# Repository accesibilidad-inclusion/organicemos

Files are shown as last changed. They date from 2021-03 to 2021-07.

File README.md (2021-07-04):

# Organicemos

## Contexto

[Para mayor información acerca de la investigación acerca de la investigación realizada en el proyecto de Apoyos a la vida independiente de adultos con discapacidad intelectual haga click aquí](https://wiki.ead.pucv.cl/Apoyos_a_la_vida_independiente_de_adultos_con_discapacidad_intelectual:_Organizador_colaborativo)

La vida independiente es considerada un derecho de las personas con discapacidad, además de ser un factor clave para el fomento de la calidad de vida de estas personas. Esta investigación se desarrolla en Chile, país en el que no se encuentran tan desarrolladas las materias de derechos ni oportunidades para la vida independiente de este grupo históricamente vulnerado. 

El panorama internacional actual demuestra que el uso de tecnologías asistivas como apoyo para diversos aspectos de la vida de las personas con discapacidad, pueden llegar a generar un cambio positivo en sus vidas.

Dentro de este mundo, se suelen encontrar aquellas que apoyan las funciones primarias de la vida de estas personas, las cuales se desarrollan en base a un estudio de sus capacidades. En este proyecto, a través de un proceso de diseño participativo, interdisciplinario e inclusivo se identifican las necesidades que las mismas personas con DI sienten importantes para fomentar su vida independiente. **Una de las necesidades sentidas por este grupo es la necesidad de apoyo para la organización.**

## Pizarra de organización colaborativa

[Para ingresar al repositorio de GitHub de Organicemos haga click aquí](https://github.com/accesibilidad-inclusion/organicemos/tree/gh-pages)

‘Organicemos’ es un organizador colaborativo, diseñado para **fomentar la participación de grupos convivientes a través de un sistema de tareas equitativo.** Este se ajusta a dos contextos de distinta escala, el primero se sitúa en una vivienda familiar. Este artefacto propone al grupo un plan semanal en base a las diversas capacidades de cada integrante y las tareas necesarias a realizar en el hogar, igualmente por medio de la confirmación de éstas se lleva un registro de aquellas tareas cumplidas y no cumplidas. Cumple además con la función de recordar a cada persona sus quehaceres en el momento que deben ser realizados, vuelve eficiente la organización de un espacio compartido.

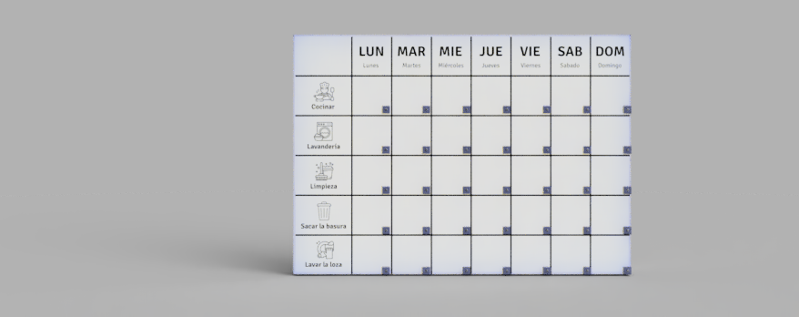
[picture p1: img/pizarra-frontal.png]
Pizarra frontal


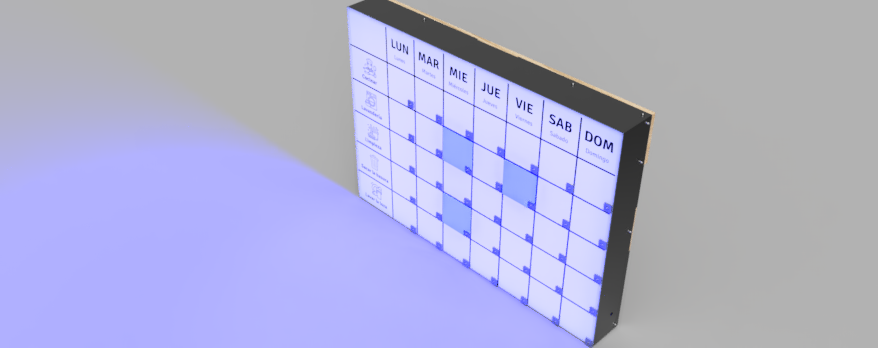
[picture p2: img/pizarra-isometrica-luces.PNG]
Pizarra isométrica


## Sistema electrónico

El sistema electrónico del prototipo Organicemos se basa principalmente en el encendido y apagado de luces, el cual funciona a través de un sistema de sensores capacitivos los cuales se relacionan con el usuario por medio de pernos que funcionan como botones generando el cambio en las luces.

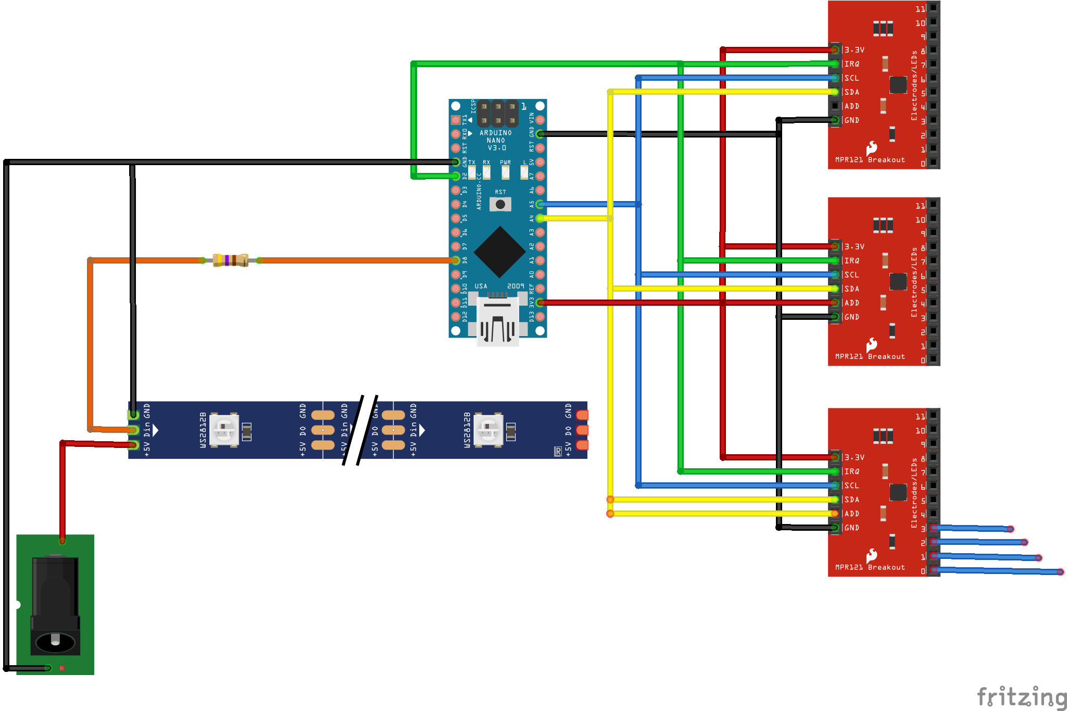
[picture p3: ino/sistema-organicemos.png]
Imagen del sistema
*En la imagen se muestran las conexiones electrónicas de los componentes del aparato para su funcionamiento*

##Validación interna

Tras la revisión del primer prototipo formal, se propone un proceso de validación, una evaluación que conste de tres niveles, comenzando con una **validación interna por parte del equipo desarrollador de los prototipos,** para luego dar cabida a una evaluación por parte del G.A -grupo asesor- y finalmente terminar con una evaluación en residencias.

Lo que se busca con esto, es que entre evaluaciones se puedan ir aplicando mejoras según las experiencias de cada usuario que lo testee, y que de esta manera, pueda llegar a un estado óptimo en cuanto a diseño y funcionalidad.

1. Las acciones de **encendido/apagado** no funcionan correctamente, lo cual dificulta probar la función principal de este prototipo.
2. La sensibilidad de los botones (este problema puede ser causa del anterior)

Debido a los problemas que han ocurrido por la sensibilidad de los sensores, se realizan pruebas con otros materiales, como cinta adhesiva de cobre, también se realizan pruebas desconectando las distintas partes del sistema electrónico. 
Durante estas pruebas se llega a la conclusión que el material del prototipo, ya sea de programación o del sistema electrónico, no se encuentran ordenados de manera que facilite el trabajo posterior con este. Es por esto que se propone un orden para entender la relación entre los sensores y las luces del panel.

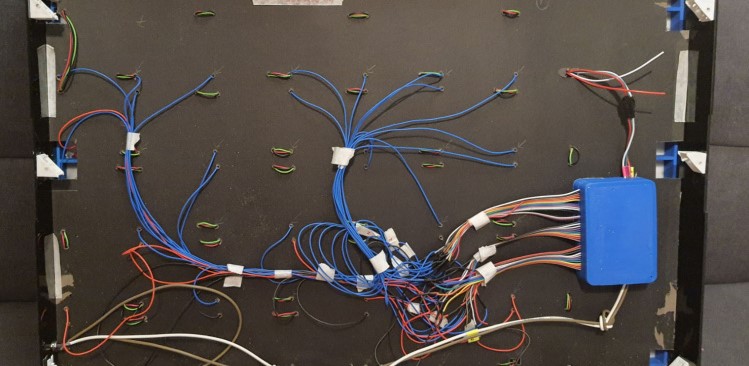
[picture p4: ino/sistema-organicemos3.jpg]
Imagen del sistema
*En la imagen se muestra el cableado del sistema electrónico interno del Organicemos*

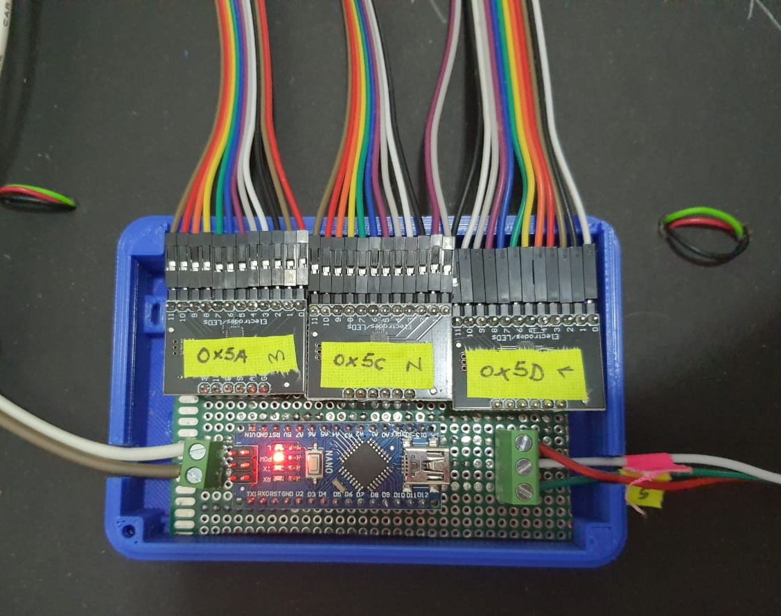
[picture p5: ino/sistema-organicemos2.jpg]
Imagen del sistema
*En la imagen se muestran los sensores MPR121 y la placa Arduino*

Para solucionar este problema y facilitar el futuro trabajo con el prototipo se propone un sistema de orden según colores, teniendo cada sensor un color asignado.

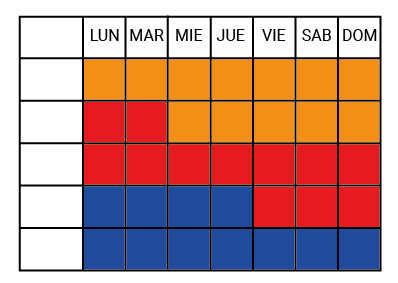
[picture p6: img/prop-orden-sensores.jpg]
Orden para luces
*Relación de color entre el panel y los sensores*

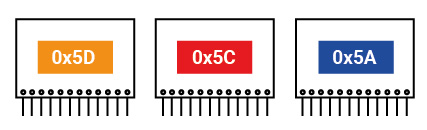
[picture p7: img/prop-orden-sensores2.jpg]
Etiqueta para sensores
*Color asignado a cada sensor*

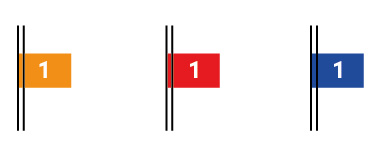
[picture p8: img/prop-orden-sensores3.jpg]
Etiqueta para cables
*Etiqueta en cada cable con el fin de reconocer que luz está encendiendo*

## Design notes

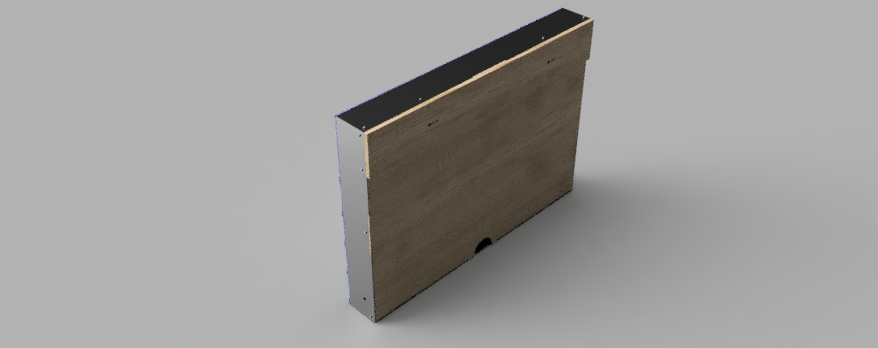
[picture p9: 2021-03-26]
img/pizarra-isometrica-posterior.png

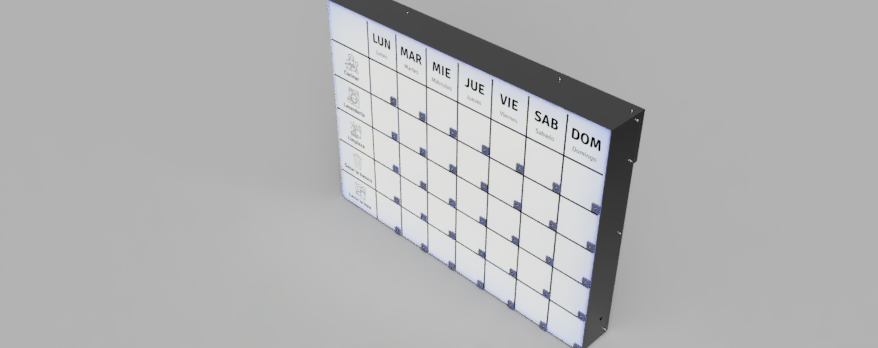
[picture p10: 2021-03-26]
img/pizarra-isometrica.png

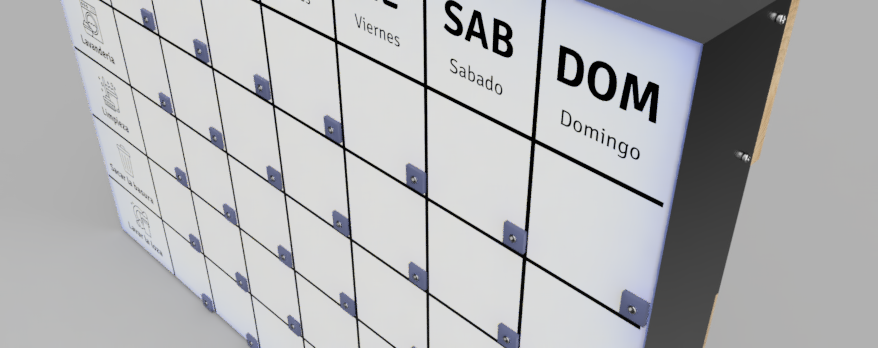
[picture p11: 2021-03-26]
img/pizarra-detalle.png

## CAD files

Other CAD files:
3d/pizarra.f3z

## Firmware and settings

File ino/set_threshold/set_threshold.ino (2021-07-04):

#include <Wire.h>
#include "Adafruit_MPR121.h"

#ifndef _BV
#define _BV(bit) (1 << (bit)) 
#endif

// You can have up to 4 on one i2c bus but one is enough for testing!
Adafruit_MPR121 cap = Adafruit_MPR121();

// Keeps track of the last pins touched
// so we know when buttons are 'released'
uint16_t lasttouched = 0;
uint16_t currtouched = 0;

uint8_t set_touch = 0X05;
uint8_t set_realese = 0X05;  

void setup() {
  Serial.begin(9600);

  while (!Serial) { // needed to keep leonardo/micro from starting too fast!
    delay(10);
  }
  
  Serial.println("Adafruit MPR121 Capacitive Touch sensor test"); 
  
  // Default address is 0x5A, if tied to 3.3V its 0x5B
  // If tied to SDA its 0x5C and if SCL then 0x5D
  if (!cap.begin(0x5A)) {
    Serial.println("MPR121 not found, check wiring?");
    while (1);
  }
  Serial.println("MPR121 found!");
  
  setThresholds(set_touch,set_realese)
  
}

void loop() {
  // Get the currently touched pads
  currtouched = cap.touched();
  
  for (uint8_t i=0; i<12; i++) {
    // it if *is* touched and *wasnt* touched before, alert!
    if ((currtouched & _BV(i)) && !(lasttouched & _BV(i)) ) {
      Serial.print(i); Serial.println(" touched");
    }
    // if it *was* touched and now *isnt*, alert!
    if (!(currtouched & _BV(i)) && (lasttouched & _BV(i)) ) {
      Serial.print(i); Serial.println(" released");
    }
  }

  // reset our state
  lasttouched = currtouched;

  // comment out this line for detailed data from the sensor!
  return;
  
  // debugging info, what
  Serial.print("\t\t\t\t\t\t\t\t\t\t\t\t\t 0x"); Serial.println(cap.touched(), HEX);
  Serial.print("Filt: ");
  for (uint8_t i=0; i<12; i++) {
    Serial.print(cap.filteredData(i)); Serial.print("\t");
  }
  Serial.println();
  Serial.print("Base: ");
  for (uint8_t i=0; i<12; i++) {
    Serial.print(cap.baselineData(i)); Serial.print("\t");
  }
  Serial.println();
  
  // put a delay so it isn't overwhelming
  delay(100);
}

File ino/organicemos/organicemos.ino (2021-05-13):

#include <Wire.h>
#include "Adafruit_MPR121.h"
#include <Adafruit_NeoPixel.h>
#include <avr/power.h>


#ifndef _BV
#define _BV(bit) (1 << (bit)) 
#endif
Adafruit_MPR121 cap1= Adafruit_MPR121(); //(0x5A);
Adafruit_MPR121 cap2= Adafruit_MPR121(); //(0x5C);
Adafruit_MPR121 cap3= Adafruit_MPR121(); //(0x5D);

#define PIN 6
#define NUMPIXELS      105   
Adafruit_NeoPixel pixels = Adafruit_NeoPixel(NUMPIXELS, PIN, NEO_GRB + NEO_KHZ800);
int k;
int BRILLO=30; //0 a 255

uint16_t lasttouched1 = 0;
uint16_t lasttouched2 = 0;
uint16_t lasttouched3 = 0;
uint16_t currtouched_mod1 = 0;
uint16_t currtouched_mod2 = 0;
uint16_t currtouched_mod3 = 0;

int EST1=0;int EST2=0;int EST3=0;int EST4=0;int EST5=0;int EST6=0;int EST7=0;int EST8=0;int EST9=0;int EST10=0;int EST11=0;int EST12=0;
int EST13=0;int EST14=0;int EST15=0;int EST16=0;int EST17=0;int EST18=0;int EST19=0;int EST20=0;int EST21=0;int EST22=0;int EST23=0;int EST24=0;
int EST25=0;int EST26=0;int EST27=0;int EST28=0;int EST29=0;int EST30=0;int EST31=0;int EST32=0;int EST33=0;int EST34=0;int EST35=0;int EST36=0;


  // pixels.Color toma valores en RGB, desde 0,0,0 hasta 255,255,255
   uint32_t rojo = pixels.Color(200,0,0);
   uint32_t verde = pixels.Color(0,200,0);
   uint32_t azul = pixels.Color(0,0,200);
   //Variamos los colores de cada led en nuestra cinta RGB cada medio segundo
   uint32_t amarillo = pixels.Color(200,200,0);
   uint32_t morado = pixels.Color(200,0,200);
   uint32_t celeste = pixels.Color(0,200,200);
   uint32_t blanco = pixels.Color(200,200,200);
//-------------------------------------------------------------ACÁ ESTABLECEMOS LOS COLORES DE LOS ESTADOS
  uint32_t COLOR1=azul;
 // uint32_t COLOR2=rojo;
 // uint32_t COLOR3=celeste;
  uint32_t APAGADO=pixels.Color(0,0,0);;
  int delayval = 100; 
//--------------------------------------------------------------



void setup()
{  
  pixels.begin();
  pixels.clear();
  for(int i=0;i<106;i++)
  {   
   pixels.setPixelColor(i*2,morado); // Brillo moderado en azul
   pixels.show();   // Mostramos y actualizamos el color del pixel de nuestra cinta led RGB
   delay(delayval); // Pausa por un periodo de tiempo (en milisegundos).
   pixels.clear(); //BORRA LOS LEDS ENCENDIDOS
  }
  pixels.clear();
  pixels.show(); 
  
  Serial.begin(9600);  
  while (!Serial) 
  { // needed to keep leonardo/micro from starting too fast!
    delay(10);
  }  
  Serial.println("Adafruit MPR121 Capacitive Touch sensor test"); 
    
  if (!cap1.begin(0x5D)) 
  {
    Serial.println("MPR121_MOD1 not found, check wiring?");
    while (1);
  }
  Serial.println("MPR121_MOD1 found!");  
  
  if (!cap2.begin(0x5C)) 
  {
    Serial.println("MPR121_MOD2 not found, check wiring?");
    while (1);
  }
  Serial.println("MPR121_MOD2 found!");   
   if (!cap3.begin(0x5A)) 
  {
    Serial.println("MPR121_MOD3 not found, check wiring?");
    while (1);
  }
  Serial.println("MPR121_MOD3 found!");   
}
void loop()
{

NOT();

}

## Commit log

2021-03-26 elimine los archivos de prueba
2021-03-26 caperta fzz
    [organicemos.fzz]
2021-03-26 carpeta 3d
    [pizarra.f3z]
2021-03-28 IMG sistema arduino
